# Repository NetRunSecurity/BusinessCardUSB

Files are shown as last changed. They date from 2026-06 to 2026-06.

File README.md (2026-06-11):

# USB Business Card (CH552G)

A real, working USB business card. It's shaped like a card, but the bottom edge is
cut into a USB-A male connector, plug it straight into any port, no cable, no
adapter. Powered by a **CH552G** with **native USB** (no USB-to-serial bridge chip),
two **capacitive touch** pads, a status LED, and a UART debug header.

It's a business card, a hacking tool, and a flex in one.

📖 Full build write-up, schematics and pinout:
**<https://wiki.netrunsecurity.com/electronics/sao/business-card/>**

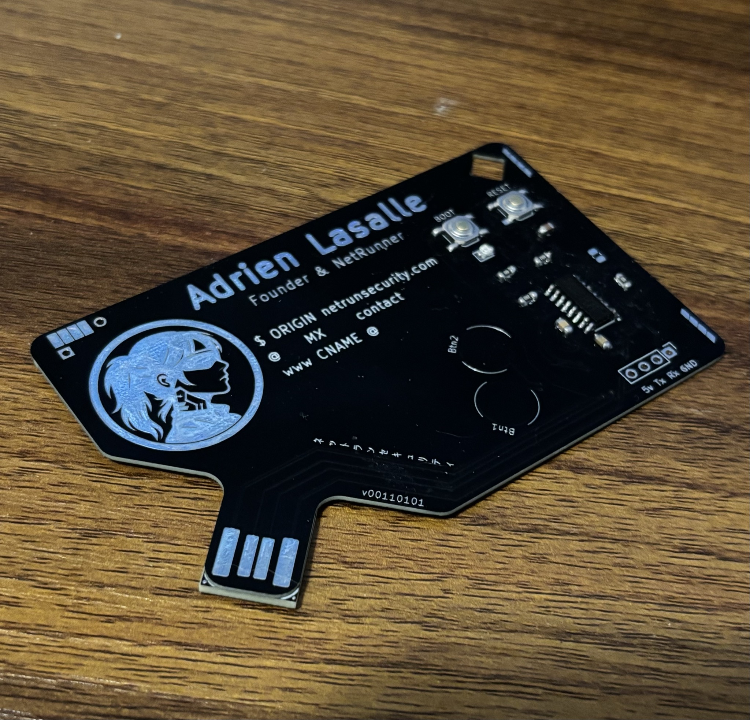
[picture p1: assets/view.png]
View Soldered


---

## What's in this repo

```
.
├─ hardware/
│  ├─ card/
│  │  ├─ v4/          # current editable KiCad design (source of truth)
│  │  └─ v3/          # validated production build, gerbers only
│  └─ shim/           # USB-tab PCB shim (KiCad source + gerbers)
├─ firmware/
│  ├─ rubber-ducky/   # HID keystroke injection (opens a URL on plug-in)
│  ├─ touchpad-testing/ # capacitive Touch-Key + LED demo
│  ├─ ctf/            # USB serial CLI with hidden flags
│  └─ usb-uart-bridge/ # USB ↔ UART bridge for debugging IoT targets
├─ docs/              # photos, schematic PDF, fabrication files (BOM)
├─ LICENSE            # TAPR OHL 1.0, hardware
└─ firmware/LICENSE   # GPL-3.0, firmware
```

## Versions

| Version | Status | Files |
| --- | --- | --- |
| **V3** | Soldered & tested, the build in the photos | Gerbers (archived) |
| **V4** | Same circuit, current revision | Full KiCad sources |

V3 and V4 are **electrically identical**. R6 was a redundant RST pull-down (R5
already pulls RST to VCC) and was left unpopulated on V3, so it never affected the
circuit. V4 removes the footprint to prevent accidental population and updates the
silkscreen text. The V4 sources faithfully represent the validated V3 build.

> ⚠️ The original `v00110100` board had a reversed USB edge-connector polarity that
> destroyed chips on plug-in. **Do not fabricate that revision.** Use V3/V4.

## Hardware

- **MCU:** WCH CH552G (8051 core, native USB)
- **USB:** PCB-edge USB-A male connector, no bridge IC
- **Input:** 2× capacitive Touch-Key pads (read through the solder mask)
- **Indicator:** status LED
- **Debug / flash:** 1×4 UART header + BOOT/RESET buttons
- **Mechanical:** card + glued USB-tab shim (~2.4 mm total) for a snug USB-A fit
- **EDA:** KiCad

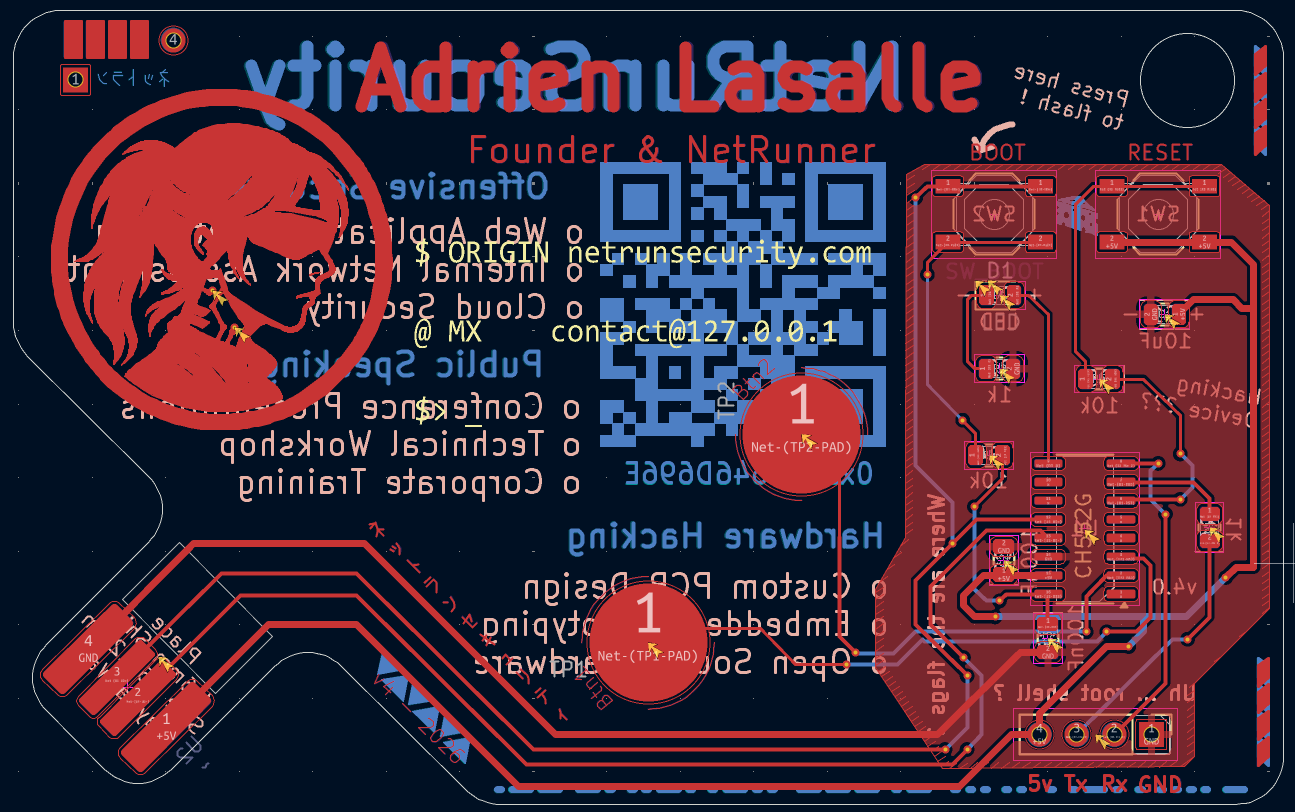
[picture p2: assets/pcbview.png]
PCB View


## Bill of Materials

| Ref | Qty | Value / Part | Package | MPN | LCSC |
| --- | --- | --- | --- | --- | --- |
| U1 | 1 | CH552G — 8-bit USB MCU | SOP-16 | CH552G | [C111292](https://www.lcsc.com/product-detail/C111292.html) |
| C1 | 1 | 10 µF 16 V X5R | 0805 | CL21A106KOQNNNE | [C1713](https://www.lcsc.com/product-detail/C1713.html) |
| C2, C3 | 2 | 100 nF 50 V X7R | 0805 | CC0805KRX7R9BB104 | [C49678](https://www.lcsc.com/product-detail/C49678.html) |
| R1, R2 | 2 | 1 kΩ 1% | 0805 | 0805W8F1001T5E | [C17513](https://www.lcsc.com/product-detail/C17513.html) |
| R4, R5 | 2 | 10 kΩ 1% | 0805 | 0805W8F1002T5E | [C17414](https://www.lcsc.com/product-detail/C17414.html) |
| D1 | 1 | Red LED 630 nm | 0805 | NCD0805R1 | [C84256](https://www.lcsc.com/product-detail/C84256.html) |
| SW1, SW2 | 2 | Tactile switch SPST | SMD 5.2×5.2 mm | TL3342F260QG | [C2886894](https://www.lcsc.com/product-detail/C2886894.html) |
| J2 | 1 | 1×4 pin header 2.54 mm (UART) | THT | HX PH254-01-04 | [C52016392](https://www.lcsc.com/product-detail/C52016392.html) |

> R6 is not populated (removed in V4). TP1/TP2 are copper touch pads and U2 is the
> PCB-edge USB connector — neither is a placed part.

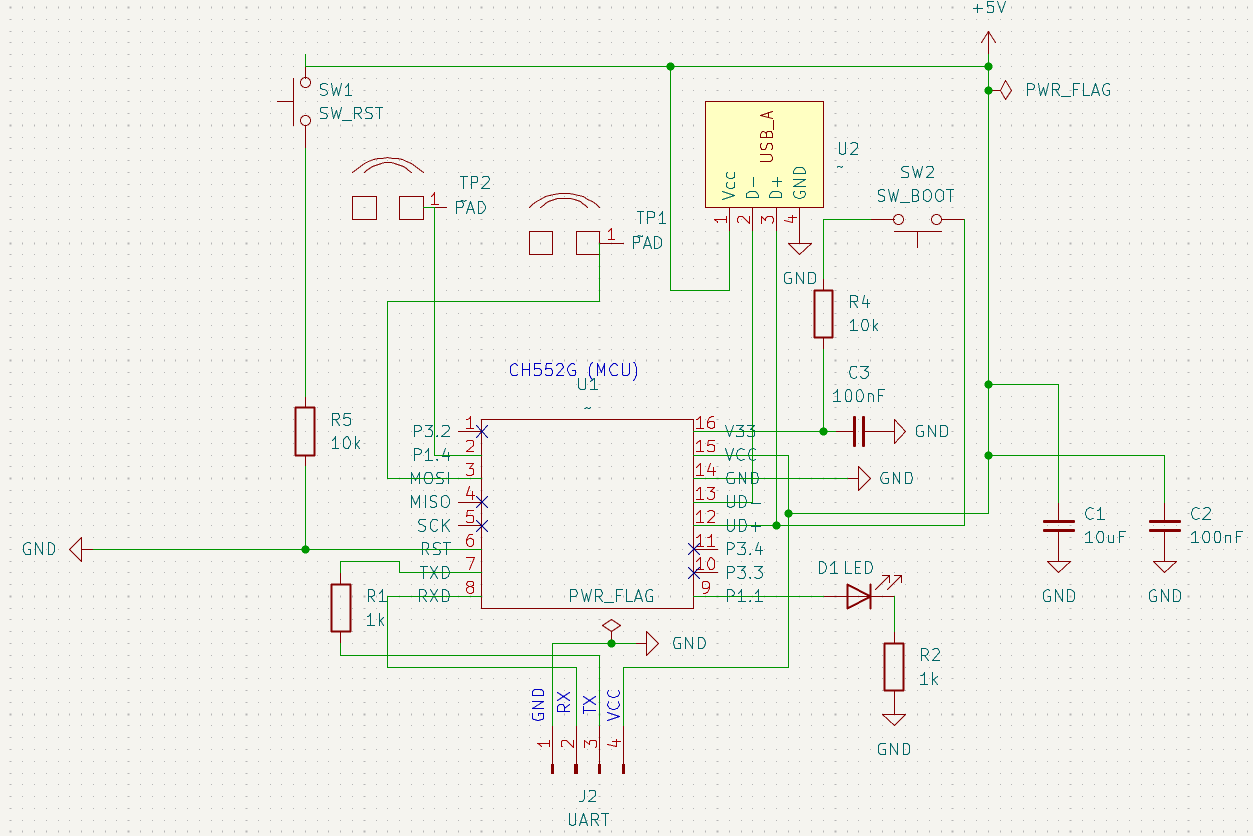
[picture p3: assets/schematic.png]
schematic view


## Firmware

Several firmwares, each demoing a different capability of the platform:

- **rubber-ducky**: enumerates as a USB keyboard and types a payload (opens a URL).
- **touchpad-testing**:  exercises the two Touch-Key pads and the LED.
- **ctf**: exposes a USB serial CLI with a small command set and hidden flags.
- **usb-uart-bridge**: bridges the on-board UART to the host for field debugging.

Build & flash instructions are in [`firmware/README.md`](firmware/README.md)
(Arduino IDE 2.x + ch55xduino).

## Fabricate / assemble your own

1. Send the gerbers in `hardware/card/v4/` (or `v3/`) to any fab.
2. Order parts from the assembly BOM in `docs/` (LCSC part numbers included).
3. Glue the shim under the USB tab.
4. Flash a firmware, see `firmware/README.md`.

A few hard-won notes: hand-solder the SOP-16 (no hot air), verify USB edge-pad
polarity against the socket before ordering, and keep a USB power meter handy for
first power-up.

## License

This is open hardware, dual-licensed:

- **Hardware** (PCB design, schematic, gerbers): **TAPR Open Hardware License 1.0**, see [`LICENSE`](LICENSE).
- **Firmware** (code): **GPL-3.0**, see [`firmware/LICENSE`](firmware/LICENSE).

Derivatives welcome, credit the original and highlight your changes.

## Author

Designed by **AlrikRr**, [NetRunSecurity](https://www.netrunsecurity.com) ·
[wiki](https://wiki.netrunsecurity.com) · [linktr.ee](https://linktr.ee/alrikrr)

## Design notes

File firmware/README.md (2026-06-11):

# Firmware

Firmware for the USB Business Card (CH552G), built with the
[ch55xduino](https://github.com/DeqingSun/ch55xduino) core under **Arduino IDE 2.x**.

Full hardware, pinout and schematics:
<https://wiki.netrunsecurity.com/electronics/sao/business-card/>

## Folders

| Folder | What it does |
| --- | --- |
| `rubber-ducky/` | USB HID keystroke injection (opens a URL on plug-in) |
| `touchpad-testing/` | Capacitive Touch-Key + LED demo |
| `ctf/` | USB serial CLI with hidden flags |
| `usb-uart-bridge/`  | USB ↔ UART bridge for debugging IoT targets |

## Toolchain setup (once)

1. Install **Arduino IDE 2.x** : <https://www.arduino.cc/en/software>
2. **File → Preferences → Additional Boards Manager URLs**, add:  `https://raw.githubusercontent.com/DeqingSun/ch55xduino/ch55xduino/package_ch55xduino_mcs51_index.json`
3. **Tools → Board → Boards Manager** → search `ch55xduino` → install.

## Board settings (Tools menu)

```
Board         : CH552
Clock Source  : 16 MHz (internal)
Upload method : USB
USB Settings  : USER CODE w/ 148B USB ram
```

> ⚠️ **`USER CODE w/ 148B USB ram` is mandatory.** With any other USB setting,
> the HID / serial headers are not found and compilation fails. This is the #1 gotcha.

## Compiling

**HID / serial sketches** (`rubber-ducky`, `serial-ctf`) need the USB source files
that ship with the ch55xduino examples:

1. **File → Examples → CH55xDuino → HidKeyboard** (or the matching USB example).
2. Replace the sketch code with the `.ino` from this repo.
3. **Sketch → Verify/Compile**.

Opening the example first is required, a blank sketch is missing the USB header
sources and will not compile.

**Plain sketches** (`touch-led-test`): no example needed. Open the `.ino` and
Verify/Compile directly.

## Flashing

1. Hold **SW2 (BOOT)**, plug the card in, release after ~1 s.
2. Device enumerates as `VID_4348 PID_55E0`.
3. **Sketch → Upload**, or flash the built binary with
   [WCHISPTool](https://www.wch-ic.com/downloads/WCHISPTool_Setup_exe.html).
4. Unplug / replug to run.

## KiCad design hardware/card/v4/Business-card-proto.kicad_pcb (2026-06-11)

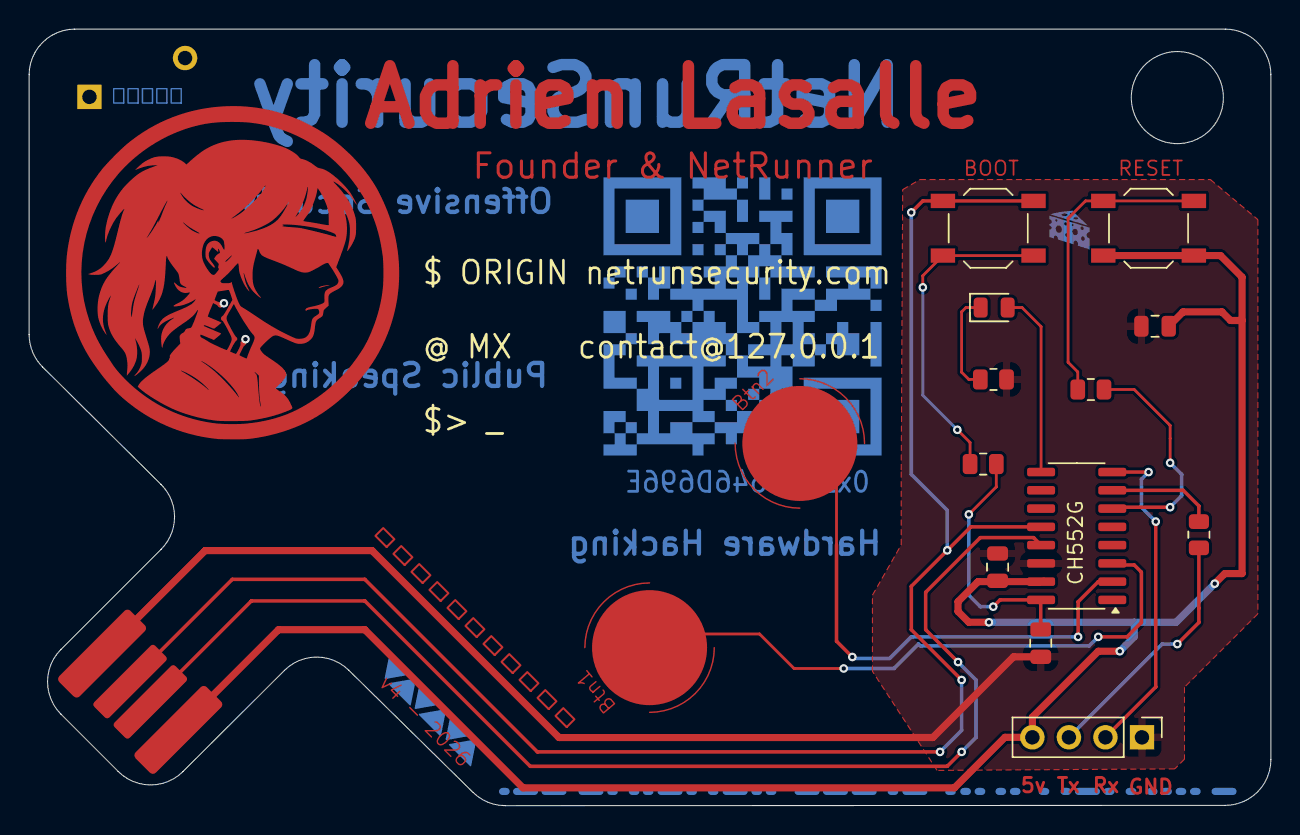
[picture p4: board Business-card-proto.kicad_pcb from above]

Board: 2 copper layers, 86.3 x 54.0 mm, 15 parts (1 on the bottom side), 15 nets.

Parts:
C1: 10uF; C_0805_2012Metric
C2, C3: 100nF; C_0805_2012Metric
D1: LED; LED_0805_2012Metric
J2: UART; PinHeader_1x04_P2.54mm_Vertical
R1, R2: 1k; R_0805_2012Metric
R4, R5: 10k; R_0805_2012Metric
SW1: SW_RST; SW_SPST_TL3342
SW2: SW_BOOT; SW_SPST_TL3342
TP1, TP2: TouchPad_Circle_10mm
U1: SOIC-16_3.9x9.9mm_P1.27mm
U2: PCB_USB

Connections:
+5V: C1.1, C2.1, J2.4, SW1.2, U1.15 (VCC), U2.1 (Vcc)
GND: C1.2, C2.2, C3.2, J2.1, R2.2, U1.14 (GND), U2.4 (GND)
unnamed: D1.2 (A), U1.9 (P1.1)
unnamed: D1.1 (K), R2.1
unnamed: J2.2, U1.8 (RXD)
unnamed: J2.3, R1.2
unnamed: R4.1, SW2.2
unnamed: R5.1, SW1.1
unnamed: TP1.1 (PAD), U1.3 (MOSI)
unnamed: TP2.1 (PAD), U1.2 (P1.4)
unnamed: R5.2, U1.6 (RST)
unnamed: R1.1, U1.7 (TXD)
unnamed: SW2.1, U1.12 (UD+), U2.3 (D+)
unnamed: U1.13 (UD-), U2.2 (D-)
unnamed: C3.1, R4.2, U1.16 (V33)

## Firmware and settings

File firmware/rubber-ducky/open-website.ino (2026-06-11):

#ifndef USER_USB_RAM
#error "This example needs to be compiled with a USER USB setting"
#endif

#include "src/userUsbHidKeyboard/USBHIDKeyboard.h"

#define LED_PIN 33  // P1.1

void setup() {
  USBInit();
  pinMode(LED_PIN, OUTPUT);

  // Startup signal — 3 blinks
  for (int i = 0; i < 3; i++) {
    digitalWrite(LED_PIN, HIGH);
    delay(200);
    digitalWrite(LED_PIN, LOW);
    delay(200);
  }

  delay(2000); // Wait for HID to be recognized by the PC

  // Win + R to open Run dialog
  Keyboard_press(KEY_LEFT_GUI);
  Keyboard_press('r');
  delay(100);
  Keyboard_releaseAll();
  delay(500);

  // Type the URL
  Keyboard_print("https://www.netrunsecurity.com/");
  delay(200);

  // Enter
  Keyboard_press(KEY_RETURN);
  delay(100);
  Keyboard_releaseAll();

  // LED stays on = payload sent
  digitalWrite(LED_PIN, HIGH);
}

void loop() {
  // One-shot payload, nothing to do here
}

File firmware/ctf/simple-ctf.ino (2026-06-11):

#include <TouchKey.h>
#include <string.h>

// ── CTF Flags ─────────────────────────────────────────────────────────────
#define FLAG_EASY   "FLAG-UART1"
#define FLAG_HARD   "FLAG-PENTA"
#define FLAG_MORSE  "FLAG-CW"
#define FLAG_SHELL  "FLAG-SH3LL"    // bonus: découverte du shell

// ── Hardware ──────────────────────────────────────────────────────────────
#define LED_PIN    11
#define CH1        (1<<2)   // TIN2 = TP1 = "bouton 1"
#define CH2        (1<<3)   // TIN3 = TP2 = "bouton 2"

// ── Morse timing (ms) ─────────────────────────────────────────────────────
#define DOT    150
#define DASH   450
#define IGAP   150
#define CGAP   300
#define WGAP   1050

// ── Temporisations ────────────────────────────────────────────────────────
#define TOUCH_TIMEOUT   3000UL
#define MORSE_PERIOD   30000UL

// ── État touch ────────────────────────────────────────────────────────────
static uint8_t  tp1_count    = 0;
static uint8_t  tp1_prev     = 0;
static uint8_t  tp2_prev     = 0;
static uint32_t last_tp1_ms  = 0;
static uint32_t last_morse_ms = 0;

// ── Shell ─────────────────────────────────────────────────────────────────
#define CMD_BUF 20
static char    cmd_buf[CMD_BUF];
static uint8_t cmd_len = 0;

// ── Morse ─────────────────────────────────────────────────────────────────
static void m_dot() {
  digitalWrite(LED_PIN, HIGH); delay(DOT);
  digitalWrite(LED_PIN, LOW);  delay(IGAP);
}
static void m_dash() {
  digitalWrite(LED_PIN, HIGH); delay(DASH);
  digitalWrite(LED_PIN, LOW);  delay(IGAP);
}

static void morse_char(char c) {
  if (c >= 'a' && c <= 'z') c -= 32;
  switch (c) {
    case 'A': m_dot(); m_dash(); break;
    case 'B': m_dash(); m_dot(); m_dot(); m_dot(); break;
    case 'C': m_dash(); m_dot(); m_dash(); m_dot(); break;
    case 'D': m_dash(); m_dot(); m_dot(); break;
    case 'E': m_dot(); break;
    case 'F': m_dot(); m_dot(); m_dash(); m_dot(); break;
    case 'G': m_dash(); m_dash(); m_dot(); break;
    case 'H': m_dot(); m_dot(); m_dot(); m_dot(); break;
    case 'I': m_dot(); m_dot(); break;
    case 'J': m_dot(); m_dash(); m_dash(); m_dash(); break;
    case 'K': m_dash(); m_dot(); m_dash(); break;
    case 'L': m_dot(); m_dash(); m_dot(); m_dot(); break;
    case 'M': m_dash(); m_dash(); break;
    case 'N': m_dash(); m_dot(); break;
    case 'O': m_dash(); m_dash(); m_dash(); break;
    case 'P': m_dot(); m_dash(); m_dash(); m_dot(); break;
    case 'Q': m_dash(); m_dash(); m_dot(); m_dash(); break;
    case 'R': m_dot(); m_dash(); m_dot(); break;
    case 'S': m_dot(); m_dot(); m_dot(); break;
    case 'T': m_dash(); break;
    case 'U': m_dot(); m_dot(); m_dash(); break;
    case 'V': m_dot(); m_dot(); m_dot(); m_dash(); break;
    case 'W': m_dot(); m_dash(); m_dash(); break;
    case 'X': m_dash(); m_dot(); m_dot(); m_dash(); break;
    case 'Y': m_dash(); m_dot(); m_dash(); m_dash(); break;
    case 'Z': m_dash(); m_dash(); m_dot(); m_dot(); break;
    case '0': m_dash(); m_dash(); m_dash(); m_dash(); m_dash(); break;
    case '1': m_dot(); m_dash(); m_dash(); m_dash(); m_dash(); break;
    case '2': m_dot(); m_dot(); m_dash(); m_dash(); m_dash(); break;
    case '3': m_dot(); m_dot(); m_dot(); m_dash(); m_dash(); break;
    case '4': m_dot(); m_dot(); m_dot(); m_dot(); m_dash(); break;
    case '5': m_dot(); m_dot(); m_dot(); m_dot(); m_dot(); break;
    case '6': m_dash(); m_dot(); m_dot(); m_dot(); m_dot(); break;
    case '7': m_dash(); m_dash(); m_dot(); m_dot(); m_dot(); break;
    case '8': m_dash(); m_dash(); m_dash(); m_dot(); m_dot(); break;
    case '9': m_dash(); m_dash(); m_dash(); m_dash(); m_dot(); break;
    default: delay(WGAP); return;
  }
  delay(CGAP);
}

static void play_morse(const char *s) {
  uint8_t i = 0;
  while (s[i]) { morse_char(s[i]); i++; }
  delay(WGAP * 2);
}

// ── Shell ─────────────────────────────────────────────────────────────────
static void shell_exec() {
  if (strcmp(cmd_buf, "help") == 0) {
    USBSerial_println("Available commands:");
    USBSerial_println("  help    - show this message");
    USBSerial_println("  info    - chip and firmware info");
    USBSerial_println("  ping    - connectivity check");
    USBSerial_println("  uptime  - milliseconds since boot");
    USBSerial_println("  touch   - current touch pad state");
    USBSerial_println("  morse   - trigger Morse sequence now");
    USBSerial_println("  reset   - reset touch counters");

  } else if (strcmp(cmd_buf, "info") == 0) {
    USBSerial_println("Board  : CH552G (8051, 24 MHz)");
    USBSerial_println("SDK    : ch55xduino 0.0.25");
    USBSerial_println("CTF    : v1.0  |  3 flags hidden");

  } else if (strcmp(cmd_buf, "ping") == 0) {
    USBSerial_println("pong");

  } else if (strcmp(cmd_buf, "uptime") == 0) {
    uint32_t ms = millis();
    uint32_t s  = ms / 1000;
    USBSerial_print("Uptime: ");
    USBSerial_print(s);
    USBSerial_println("s");

  } else if (strcmp(cmd_buf, "touch") == 0) {
    TouchKey_Process();
    uint8_t t = TouchKey_Get();
    USBSerial_print("TP1: ");
    USBSerial_println((t & CH1) ? "touched" : "open");
    USBSerial_print("TP2: ");
    USBSerial_println((t & CH2) ? "touched" : "open");

  } else if (strcmp(cmd_buf, "morse") == 0) {
    USBSerial_println("Triggering Morse on LED...");
    play_morse(FLAG_MORSE);
    last_morse_ms = millis();

  } else if (strcmp(cmd_buf, "reset") == 0) {
    tp1_count = 0;
    USBSerial_println("Touch counters reset.");

  } else if (strcmp(cmd_buf, "flag") == 0) {
    // Commande cachée — non listée dans help
    USBSerial_println(FLAG_SHELL);

  } else {
    USBSerial_print("Unknown command: ");
    USBSerial_println(cmd_buf);
    USBSerial_println("Type 'help' for available commands.");
  }
}

static void shell_tick() {
  while (USBSerial_available()) {
    char c = (char)USBSerial_read();

    if (c == '\r' || c == '\n') {
      USBSerial_println("");
      if (cmd_len > 0) {
        cmd_buf[cmd_len] = '\0';
        shell_exec();
        cmd_len = 0;
      }
      USBSerial_print("> ");

    } else if ((c == 8 || c == 127) && cmd_len > 0) {
      cmd_len--;
      USBSerial_print("\b \b");

    } else if (c >= 32 && cmd_len < CMD_BUF - 1) {
      cmd_buf[cmd_len++] = c;
      USBSerial_write(c);   // echo
    }
  }
}

// ── Setup ─────────────────────────────────────────────────────────────────
void setup() {
  pinMode(LED_PIN, OUTPUT);
  digitalWrite(LED_PIN, LOW);

  TouchKey_begin(CH1 | CH2);
  delay(500);
  USBSerial();

  USBSerial_println("================================");
  USBSerial_println("  CH552 Business Card CTF v1.0  ");
  USBSerial_println("================================");
  USBSerial_println("3 flags to find. Good luck!");
  USBSerial_println("Type 'help' for shell commands.");
  USBSerial_println("");
  USBSerial_print("> ");

  for (uint8_t i = 0; i < 3; i++) {
    digitalWrite(LED_PIN, HIGH); delay(80);
    digitalWrite(LED_PIN, LOW);  delay(80);
  }

  last_morse_ms = millis();
}
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
